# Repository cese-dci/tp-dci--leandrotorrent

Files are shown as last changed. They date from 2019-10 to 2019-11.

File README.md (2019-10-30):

El trabajo consiste en una primera placa para el proyecto final de la CESE:
https://docs.google.com/document/d/1wCjeIKm8gcKpIWY8Q068zwM_yTZGFjd9SOWhoT_4LNc/edit?usp=sharing

El proyecto consiste en un equipo capaz de conectar dispositivos con salida de datos RS-232 o RS-485 hacia una red Ethernet. 
La placa cuenta con:
- Drivers MAX3222 e ISL83485.
- Microcontrolador MSP430F5438A .
- Memorias 24LC256 para almacenamiento de web embebida (para configuracion y monitoreo).
- Modulo WIZNET para salida de datos hacia red Ethernet.

La hoja principal del esquematico se dirige a cada una de las partes que conforman la placa, siendo estas:
- Alimentacion
- Microcontrolador
- Drivers Serie
- Memorias 
- Modulo Wiznet

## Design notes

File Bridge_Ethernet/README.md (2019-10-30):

Comenzar a ver Esquemático desde el archivo "Bridge_Ethernet.sch"

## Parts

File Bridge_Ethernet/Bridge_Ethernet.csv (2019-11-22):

Id | Designator | Package | Quantity | Designation | Supplier and ref
1 | J4,J3 | PinSocket_1x06_P2.54mm_Vertical | 2 | Conn_01x06
2 | U7 | PZ100 | 1 | MSP430F5438A
3 | J5 | PinHeader_2x07_P1.27mm_Vertical | 1 | Conn_2Rows-13Pins
4 | C1,C2,C3,C4,C5,C6,C7,C8,C9,C10,C11,C12,C13,C14,C15,C16,C17,C18,C20,C21,C22,C26,C27,C28,C29,C30,C31,C32,C33,C34,C35,C36,C37 | C_0805_2012Metric | 33 | 0.1uF
5 | C19 | C_0805_2012Metric | 1 | 470nF
6 | C23 | C_0805_2012Metric | 1 | 22uF
7 | C24 | C_0805_2012Metric | 1 | 220uF
8 | C25 | C_0805_2012Metric | 1 | 10uF
9 | D1,D2,D3,D4,D9,D10,D11,D12 | SOT95P280X125-3N | 8 | GL05T-E3-08
10 | D5 | TO-269AA | 1 | MB2S
11 | D6 | D_SOD-123 | 1 | BZT52BC30-7
12 | D7 | LED_0805_2012Metric | 1 | VCC_5V
13 | D8 | D_MiniMELF | 1 | 10MQ060N
14 | F1 | Fuse_0805_2012Metric | 1 | Polyswitch
15 | J1,J2 | PinSocket_1x04_P1.27mm_Vertical | 2 | Conn_01x04_Female
16 | J7 | PinSocket_1x04_P1.27mm_Vertical | 1 | Conn_01x04_Male
17 | L1 | L_7.3x7.3_H4.5 | 1 | 330uH
18 | R1,R2,R3,R4,R9,R10,R11,R12 | R_0805_2012Metric | 8 | 4K7
19 | R5,R6 | R_0805_2012Metric | 2 | 10K
20 | R7 | R_0805_2012Metric | 1 | 47K
21 | R8 | R_0805_2012Metric | 1 | 470
22 | U1,U3,U10,U12 | SOIC127P1032X265-20N | 4 | MAX3222CDW
23 | U2,U4,U11,U13 | SOIC127P600X175-8N | 4 | ISL83485
24 | U5,U6 | SOIC127P600X175-8N | 2 | 24LC256
25 | U8 | SOIC-14W_7.5x9mm_P1.27mm | 1 | LM2574M-5
26 | U9 | DD-3 | 1 | REG1117
27 | H1,H2,H3,H4 | MountingHole_2.5mm_Pad | 4 | MountingHole

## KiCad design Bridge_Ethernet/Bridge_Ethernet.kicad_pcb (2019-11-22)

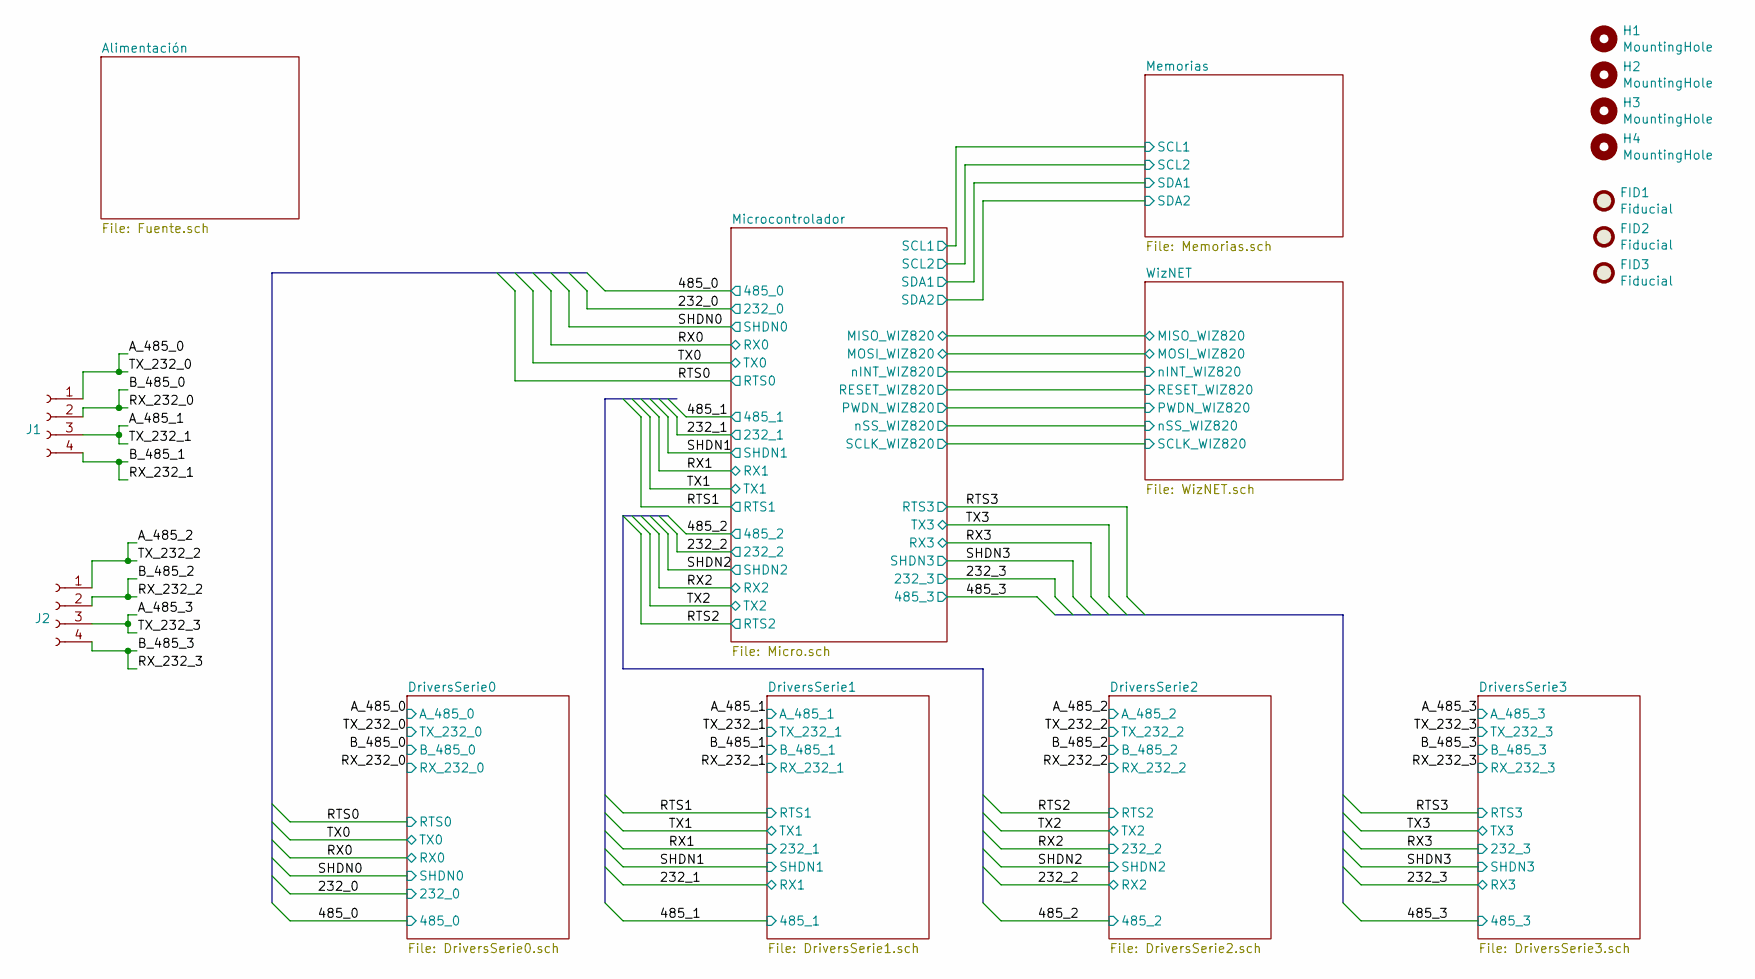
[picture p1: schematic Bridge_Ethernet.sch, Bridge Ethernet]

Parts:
FID1, FID2, FID3: Fiducial; Fiducial_0.5mm_Mask1mm
H1, H2, H3, H4: MountingHole; MountingHole_2.5mm_Pad
J1, J2: Conn_01x04_Female; PinSocket_1x04_P1.27mm_Vertical

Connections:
/A_485_0: J1.1; also elsewhere on the board
/A_485_1: J1.3; also elsewhere on the board
/A_485_2: J2.1; also elsewhere on the board
/A_485_3: J2.3; also elsewhere on the board
/B_485_0: J1.2; also elsewhere on the board
/B_485_1: J1.4; also elsewhere on the board
/B_485_2: J2.2; also elsewhere on the board
/B_485_3: J2.4; also elsewhere on the board

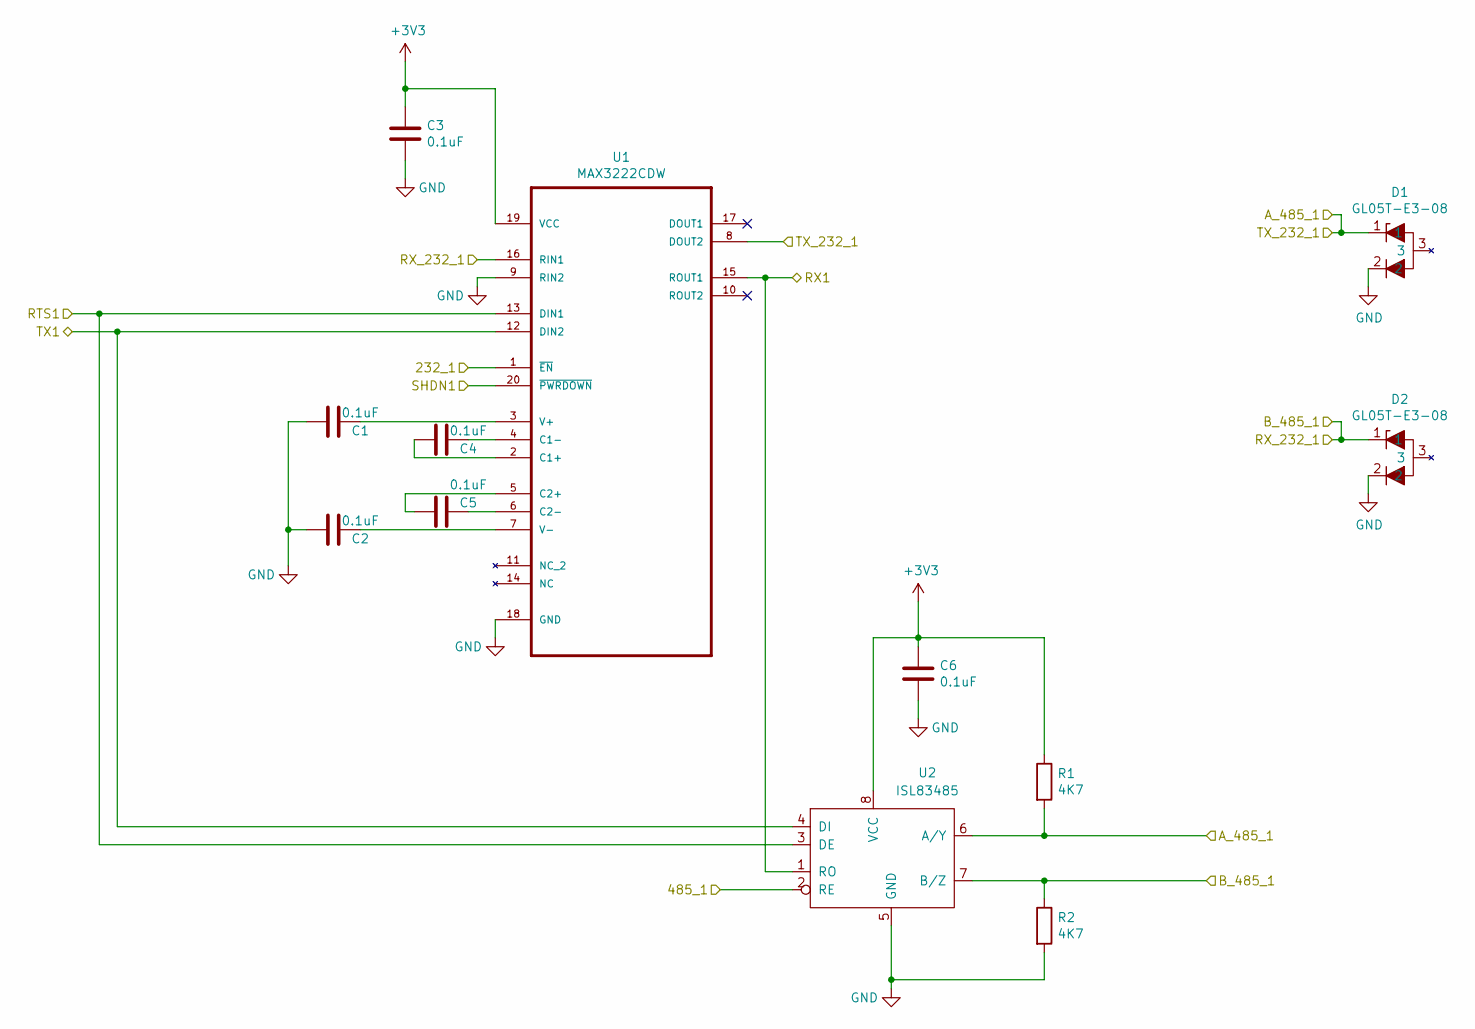
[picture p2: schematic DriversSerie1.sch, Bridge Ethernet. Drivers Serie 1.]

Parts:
C1, C2, C3, C4, C5, C6: 0.1uF; C_0805_2012Metric
D1, D2: GL05T-E3-08; SOT95P280X125-3N
R1, R2: 4K7; R_0805_2012Metric
U1: MAX3222CDW; SOIC127P1032X265-20N
U2: ISL83485; SOIC127P600X175-8N

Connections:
/232_1: U1.15 (ROUT1), U2.1 (RO); also elsewhere on the board
/485_1: U2.2 (RE); also elsewhere on the board
/A_485_1: D1.1, R1.2, U1.8 (DOUT2), U2.6 (A/Y); also elsewhere on the board
/B_485_1: D2.1, R2.1, U1.16 (RIN1), U2.7 (B/Z); also elsewhere on the board
/RTS1: U1.13 (DIN1), U2.3 (DE); also elsewhere on the board
/RX1: U1.1 (~EN); also elsewhere on the board
/SHDN1: U1.20 (~PWRDOWN); also elsewhere on the board
/TX1: U1.12 (DIN2), U2.4 (DI); also elsewhere on the board
GND: C1.2, C2.2, C3.2, C6.2, D1.2, D2.2, R2.2, U1.9 (RIN2), U1.18 (GND), U2.5 (GND); also elsewhere on the board
unnamed: C1.1, U1.3 (V+)
unnamed: C2.1, U1.7 (V-)
unnamed: C4.1, U1.4 (C1-)
unnamed: C4.2, U1.2 (C1+)
unnamed: C5.1, U1.6 (C2-)
unnamed: C5.2, U1.5 (C2+)

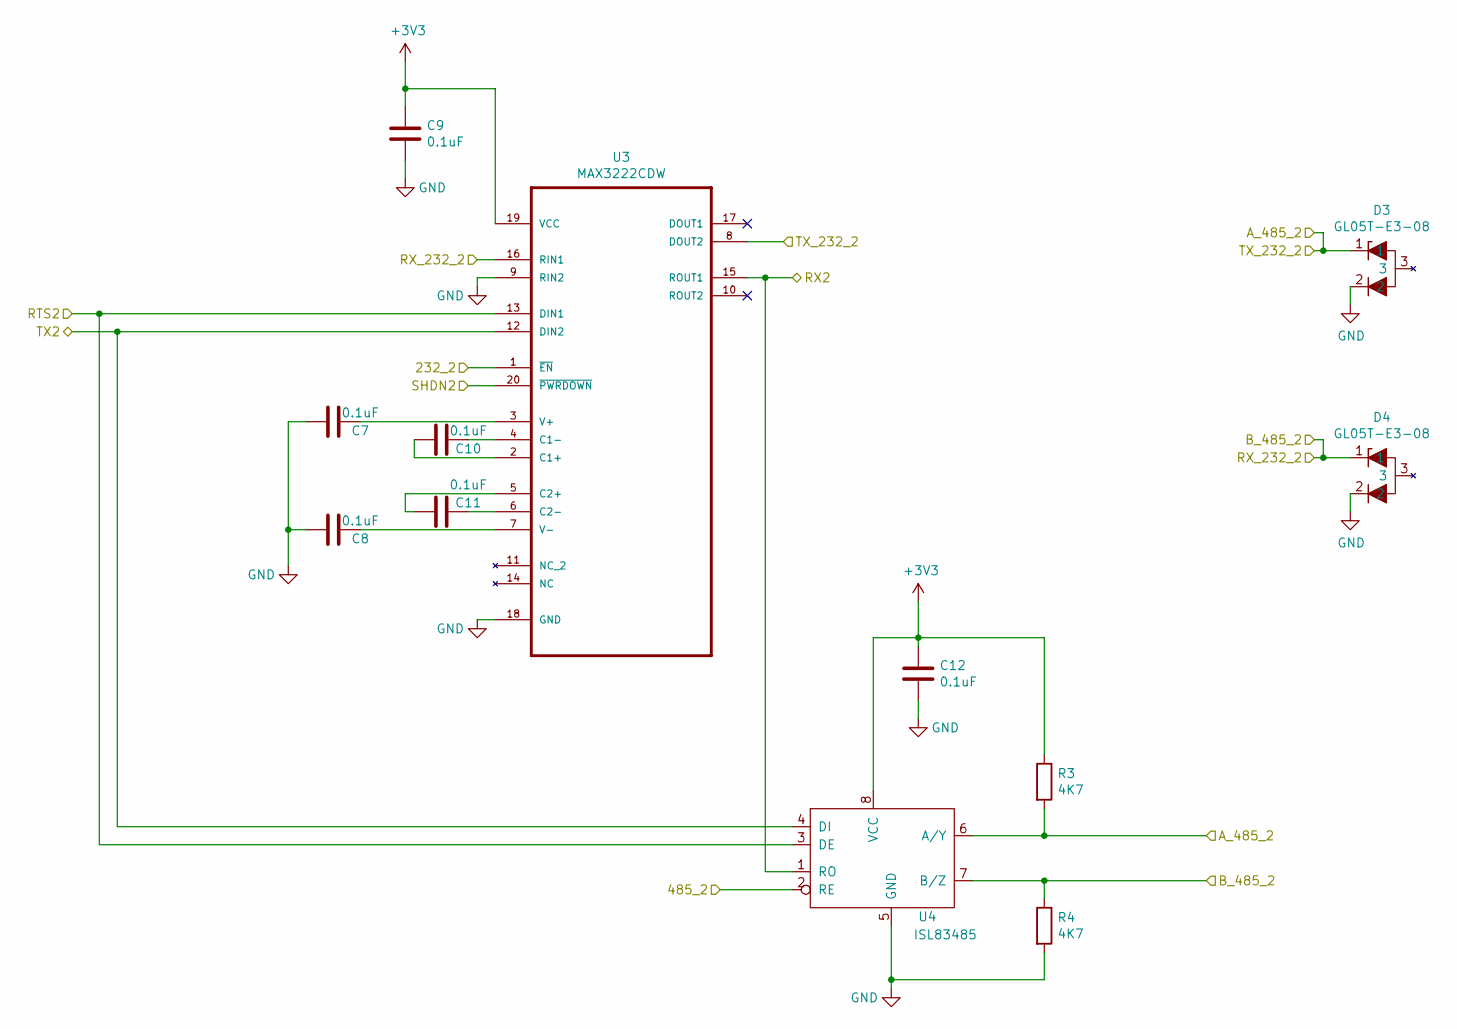
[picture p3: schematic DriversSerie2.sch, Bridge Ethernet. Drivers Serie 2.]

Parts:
C7, C8, C9, C10, C11, C12: 0.1uF; C_0805_2012Metric
D3, D4: GL05T-E3-08; SOT95P280X125-3N
R3, R4: 4K7; R_0805_2012Metric
U3: MAX3222CDW; SOIC127P1032X265-20N
U4: ISL83485; SOIC127P600X175-8N

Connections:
/232_2: U3.15 (ROUT1), U4.1 (RO); also elsewhere on the board
/485_2: U4.2 (RE); also elsewhere on the board
/A_485_2: D3.1, R3.2, U3.8 (DOUT2), U4.6 (A/Y); also elsewhere on the board
/B_485_2: D4.1, R4.1, U3.16 (RIN1), U4.7 (B/Z); also elsewhere on the board
/RTS2: U3.13 (DIN1), U4.3 (DE); also elsewhere on the board
/RX2: U3.1 (~EN); also elsewhere on the board
/SHDN2: U3.20 (~PWRDOWN); also elsewhere on the board
/TX2: U3.12 (DIN2), U4.4 (DI); also elsewhere on the board
GND: C7.2, C8.2, C9.2, C12.2, D3.2, D4.2, R4.2, U3.9 (RIN2), U3.18 (GND), U4.5 (GND); also elsewhere on the board
unnamed: C7.1, U3.3 (V+)
unnamed: C8.1, U3.7 (V-)
unnamed: C10.1, U3.4 (C1-)
unnamed: C10.2, U3.2 (C1+)
unnamed: C11.1, U3.6 (C2-)
unnamed: C11.2, U3.5 (C2+)

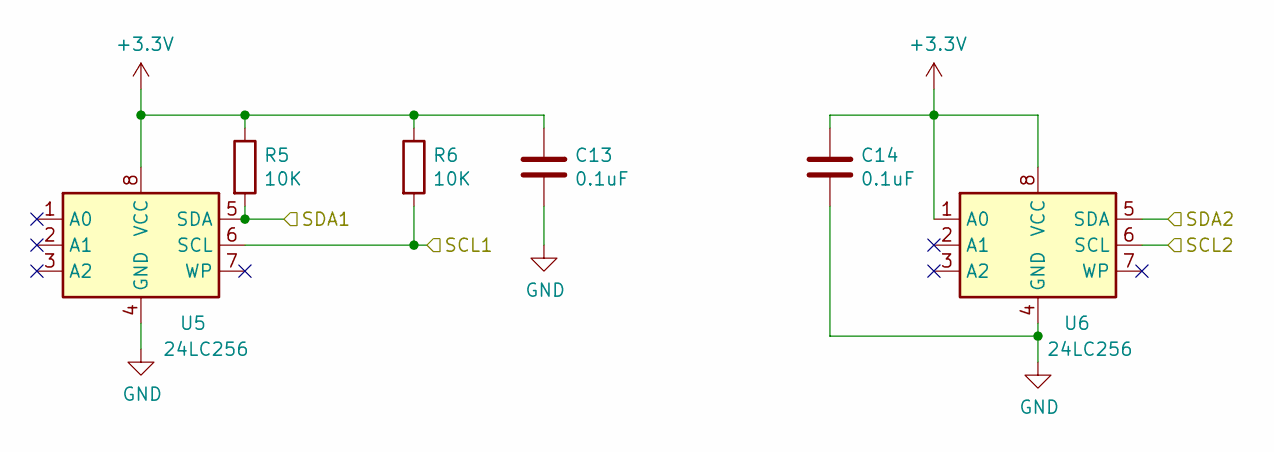
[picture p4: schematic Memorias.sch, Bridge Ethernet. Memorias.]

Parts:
C13, C14: 0.1uF; C_0805_2012Metric
R5, R6: 10K; R_0805_2012Metric
U5, U6: 24LC256; SOIC127P600X175-8N

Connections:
/Memorias/SCL1: R6.2, U5.6 (SCL); also elsewhere on the board
/Memorias/SCL2: U6.6 (SCL); also elsewhere on the board
/Memorias/SDA1: R5.2, U5.5 (SDA); also elsewhere on the board
/Memorias/SDA2: U6.5 (SDA); also elsewhere on the board
GND: C13.2, C14.2, U5.4 (GND), U6.4 (GND); also elsewhere on the board

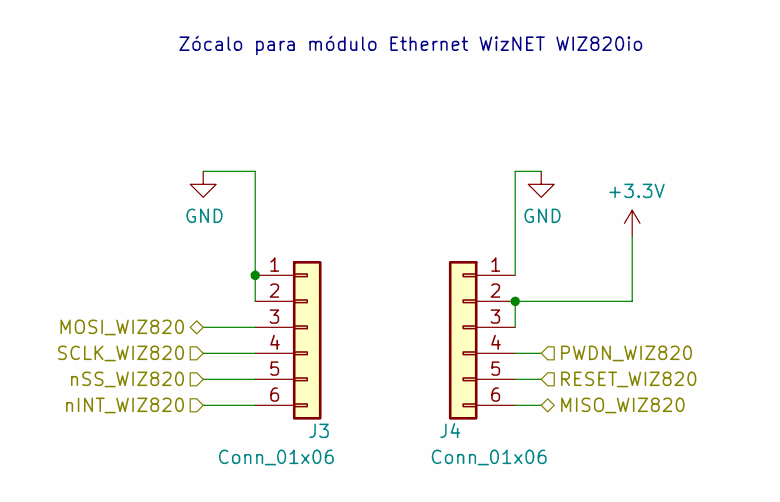
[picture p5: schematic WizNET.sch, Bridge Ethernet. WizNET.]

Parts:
J3, J4: Conn_01x06; PinSocket_1x06_P2.54mm_Vertical

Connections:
/Microcontrolador/MISO_WIZ820: J4.6; also elsewhere on the board
/Microcontrolador/MOSI_WIZ820: J3.3; also elsewhere on the board
/Microcontrolador/PWDN_WIZ820: J4.4; also elsewhere on the board
/Microcontrolador/RESET_WIZ820: J4.5; also elsewhere on the board
/Microcontrolador/SCLK_WIZ820: J3.4; also elsewhere on the board
/Microcontrolador/nINT_WIZ820: J3.6; also elsewhere on the board
/Microcontrolador/nSS_WIZ820: J3.5; also elsewhere on the board
GND: J3.1, J3.2, J4.1; also elsewhere on the board

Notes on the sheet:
Zócalo para módulo Ethernet WizNET WIZ820io

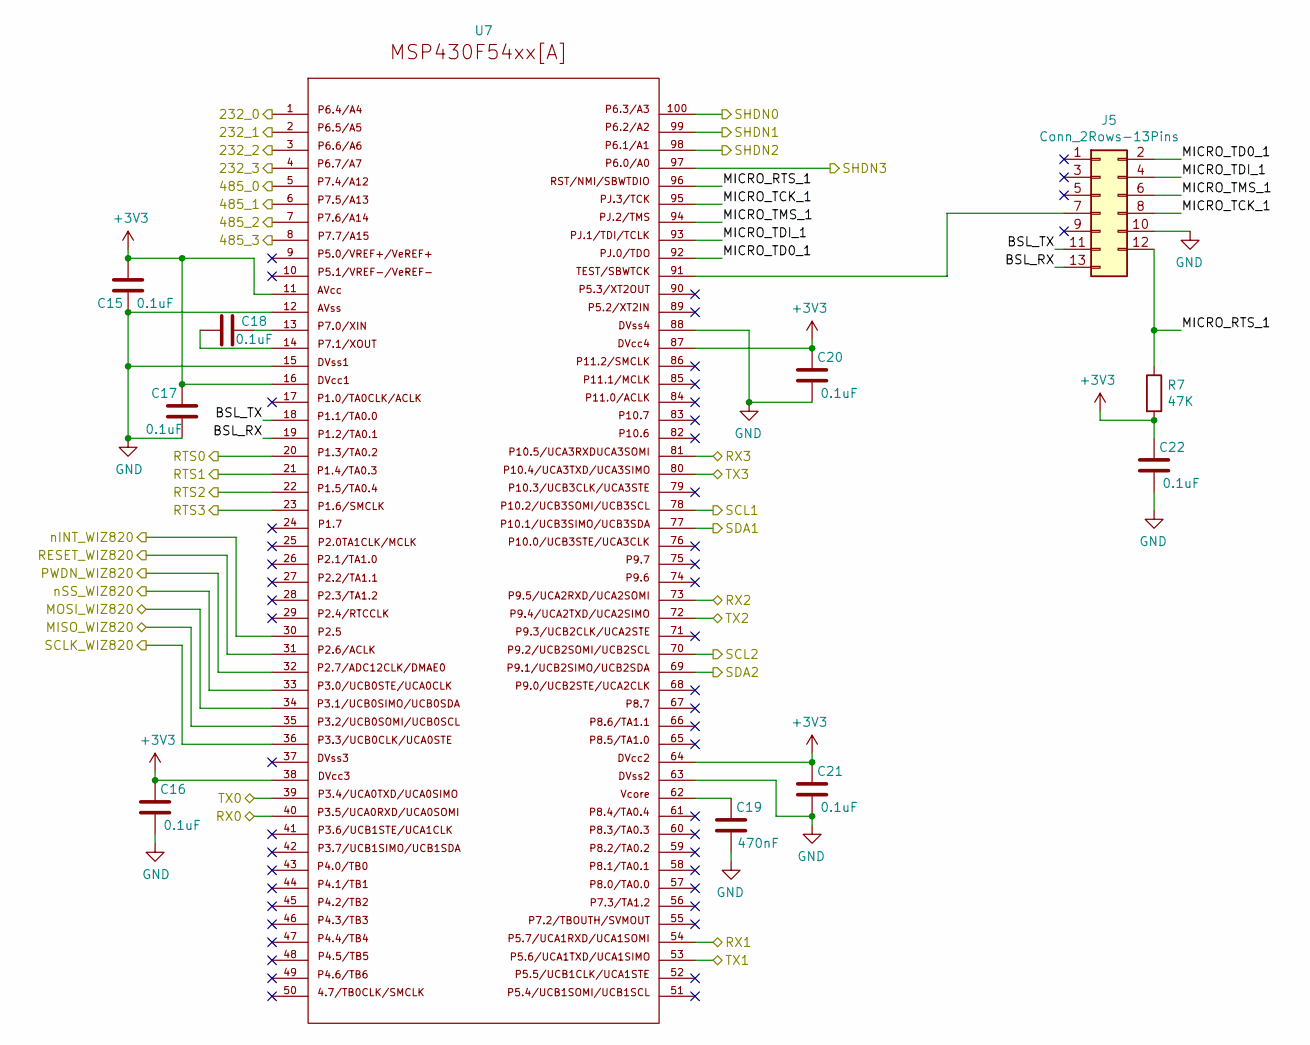
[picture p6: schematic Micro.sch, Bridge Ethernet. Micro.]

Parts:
C15, C16, C17, C18, C20, C21, C22: 0.1uF; C_0805_2012Metric
C19: 470nF; C_0805_2012Metric
J5: Conn_2Rows-13Pins; PinHeader_2x07_P1.27mm_Vertical
R7: 47K; R_0805_2012Metric
U7: MSP430F5438A; PZ100

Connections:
/232_0: U7.1; also elsewhere on the board
/232_1: U7.2; also elsewhere on the board
/232_2: U7.3; also elsewhere on the board
/232_3: U7.4; also elsewhere on the board
/485_0: U7.5; also elsewhere on the board
/485_1: U7.6; also elsewhere on the board
/485_2: U7.7; also elsewhere on the board
/485_3: U7.8; also elsewhere on the board
/Memorias/SCL1: U7.78; also elsewhere on the board
/Memorias/SCL2: U7.70; also elsewhere on the board
/Memorias/SDA1: U7.77; also elsewhere on the board
/Memorias/SDA2: U7.69; also elsewhere on the board
/Microcontrolador/BSL_RX: J5.13, U7.19
/Microcontrolador/BSL_TX: J5.11, U7.18
/Microcontrolador/MICRO_RTS_1: J5.12, R7.1, U7.96
/Microcontrolador/MICRO_TCK_1: J5.8, U7.95
/Microcontrolador/MICRO_TD0_1: J5.2, U7.92
/Microcontrolador/MICRO_TDI_1: J5.4, U7.93
/Microcontrolador/MICRO_TMS_1: J5.6, U7.94
/Microcontrolador/MISO_WIZ820: U7.35; also elsewhere on the board
/Microcontrolador/MOSI_WIZ820: U7.34; also elsewhere on the board
/Microcontrolador/PWDN_WIZ820: U7.32; also elsewhere on the board
/Microcontrolador/RESET_WIZ820: U7.31; also elsewhere on the board
/Microcontrolador/SCLK_WIZ820: U7.36; also elsewhere on the board
/Microcontrolador/nINT_WIZ820: U7.30; also elsewhere on the board
/Microcontrolador/nSS_WIZ820: U7.33; also elsewhere on the board
/RTS0: U7.20; also elsewhere on the board
/RTS1: U7.21; also elsewhere on the board
/RTS2: U7.22; also elsewhere on the board
/RTS3: U7.23; also elsewhere on the board
/RX0: U7.40; also elsewhere on the board
/RX1: U7.54; also elsewhere on the board
/RX2: U7.73; also elsewhere on the board
/RX3: U7.81; also elsewhere on the board
/SHDN0: U7.100; also elsewhere on the board
/SHDN1: U7.99; also elsewhere on the board
/SHDN2: U7.98; also elsewhere on the board
/SHDN3: U7.97; also elsewhere on the board
/TX0: U7.39; also elsewhere on the board
/TX1: U7.53; also elsewhere on the board
/TX2: U7.72; also elsewhere on the board
/TX3: U7.80; also elsewhere on the board
GND: C15.2, C16.2, C17.2, C19.2, C20.2, C21.2, C22.2, J5.10, U7.12, U7.15, U7.63, U7.88; also elsewhere on the board
unnamed: C18.1, U7.13
unnamed: C18.2, U7.14
unnamed: C19.1, U7.62
unnamed: J5.7, U7.91

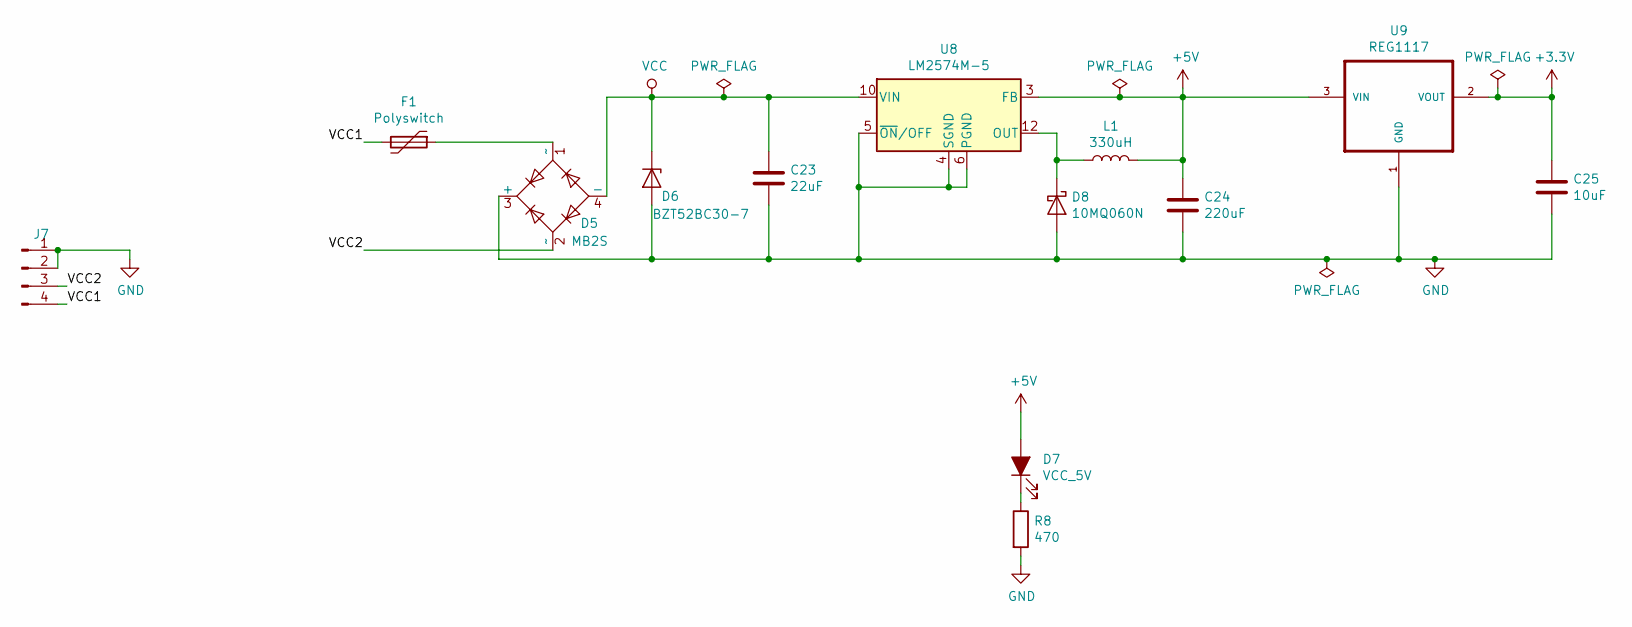
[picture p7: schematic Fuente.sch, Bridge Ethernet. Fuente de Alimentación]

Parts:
C23: 22uF; C_0805_2012Metric
C24: 220uF; C_0805_2012Metric
C25: 10uF; C_0805_2012Metric
D5: MB2S; TO-269AA
D6: BZT52BC30-7; D_SOD-123
D7: VCC_5V; LED_0805_2012Metric
D8: 10MQ060N; D_MiniMELF
F1: Polyswitch; Fuse_0805_2012Metric
J7: Conn_01x04_Male; PinSocket_1x04_P1.27mm_Vertical
L1: 330uH; L_7.3x7.3_H4.5
R8: 470; R_0805_2012Metric
U8: LM2574M-5; SOIC-14W_7.5x9mm_P1.27mm
U9: REG1117; DD-3

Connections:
+5V: C24.1, D7.2 (A), L1.2, U8.3 (FB), U9.3 (VIN)
/Alimentación/VCC1: F1.2, J7.4
/Alimentación/VCC2: D5.2 (~~), J7.3
GND: C23.2, C24.2, C25.2, D5.3 (+), D6.2 (A), D8.2 (A), J7.1, J7.2, R8.2, U8.4 (SGND), U8.5 (~ON~/OFF), U8.6 (PGND), U9.1 (GND); also elsewhere on the board
unnamed: D5.1 (~~), F1.1
unnamed: D7.1 (K), R8.1
unnamed: D8.1 (K), L1.1, U8.12 (OUT)
VCC: C23.1, D5.4 (-), D6.1 (K), U8.10 (VIN)

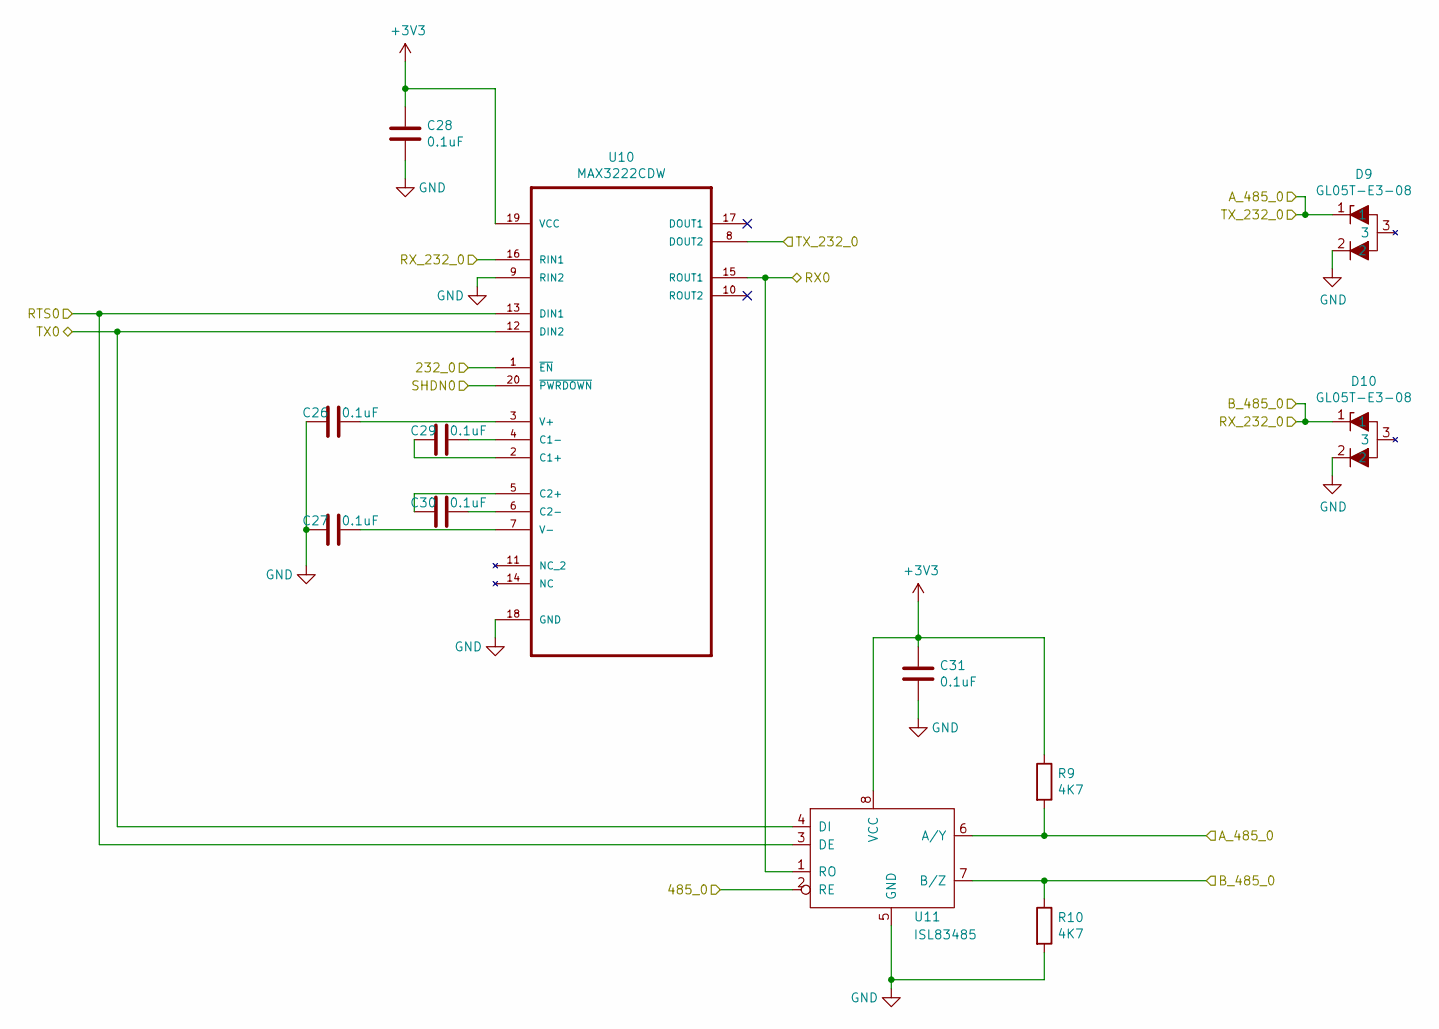
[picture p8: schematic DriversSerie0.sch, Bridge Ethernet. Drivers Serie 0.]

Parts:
C26, C27, C28, C29, C30, C31: 0.1uF; C_0805_2012Metric
D9, D10: GL05T-E3-08; SOT95P280X125-3N
R9, R10: 4K7; R_0805_2012Metric
U10: MAX3222CDW; SOIC127P1032X265-20N
U11: ISL83485; SOIC127P600X175-8N

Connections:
/232_0: U10.1 (~EN); also elsewhere on the board
/485_0: U11.2 (RE); also elsewhere on the board
/A_485_0: D9.1, R9.2, U10.8 (DOUT2), U11.6 (A/Y); also elsewhere on the board
/B_485_0: D10.1, R10.1, U10.16 (RIN1), U11.7 (B/Z); also elsewhere on the board
/RTS0: U10.13 (DIN1), U11.3 (DE); also elsewhere on the board
/RX0: U10.15 (ROUT1), U11.1 (RO); also elsewhere on the board
/SHDN0: U10.20 (~PWRDOWN); also elsewhere on the board
/TX0: U10.12 (DIN2), U11.4 (DI); also elsewhere on the board
GND: C26.2, C27.2, C28.2, C31.2, D9.2, D10.2, R10.2, U10.9 (RIN2), U10.18 (GND), U11.5 (GND); also elsewhere on the board
unnamed: C26.1, U10.3 (V+)
unnamed: C27.1, U10.7 (V-)
unnamed: C29.1, U10.4 (C1-)
unnamed: C29.2, U10.2 (C1+)
unnamed: C30.1, U10.6 (C2-)
unnamed: C30.2, U10.5 (C2+)

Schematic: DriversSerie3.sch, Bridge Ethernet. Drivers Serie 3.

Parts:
C32, C33, C34, C35, C36, C37: 0.1uF; C_0805_2012Metric
D11, D12: GL05T-E3-08; SOT95P280X125-3N
R11, R12: 4K7; R_0805_2012Metric
U12: MAX3222CDW; SOIC127P1032X265-20N
U13: ISL83485; SOIC127P600X175-8N

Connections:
/232_3: U12.15 (ROUT1), U13.1 (RO); also elsewhere on the board
/485_3: U13.2 (RE); also elsewhere on the board
/A_485_3: D11.1, R11.2, U12.8 (DOUT2), U13.6 (A/Y); also elsewhere on the board
/B_485_3: D12.1, R12.1, U12.16 (RIN1), U13.7 (B/Z); also elsewhere on the board
/RTS3: U12.13 (DIN1), U13.3 (DE); also elsewhere on the board
/RX3: U12.1 (~EN); also elsewhere on the board
/SHDN3: U12.20 (~PWRDOWN); also elsewhere on the board
/TX3: U12.12 (DIN2), U13.4 (DI); also elsewhere on the board
GND: C32.2, C33.2, C34.2, C37.2, D11.2, D12.2, R12.2, U12.9 (RIN2), U12.18 (GND), U13.5 (GND); also elsewhere on the board
unnamed: C32.1, U12.3 (V+)
unnamed: C33.1, U12.7 (V-)
unnamed: C35.1, U12.4 (C1-)
unnamed: C35.2, U12.2 (C1+)
unnamed: C36.1, U12.6 (C2-)
unnamed: C36.2, U12.5 (C2+)

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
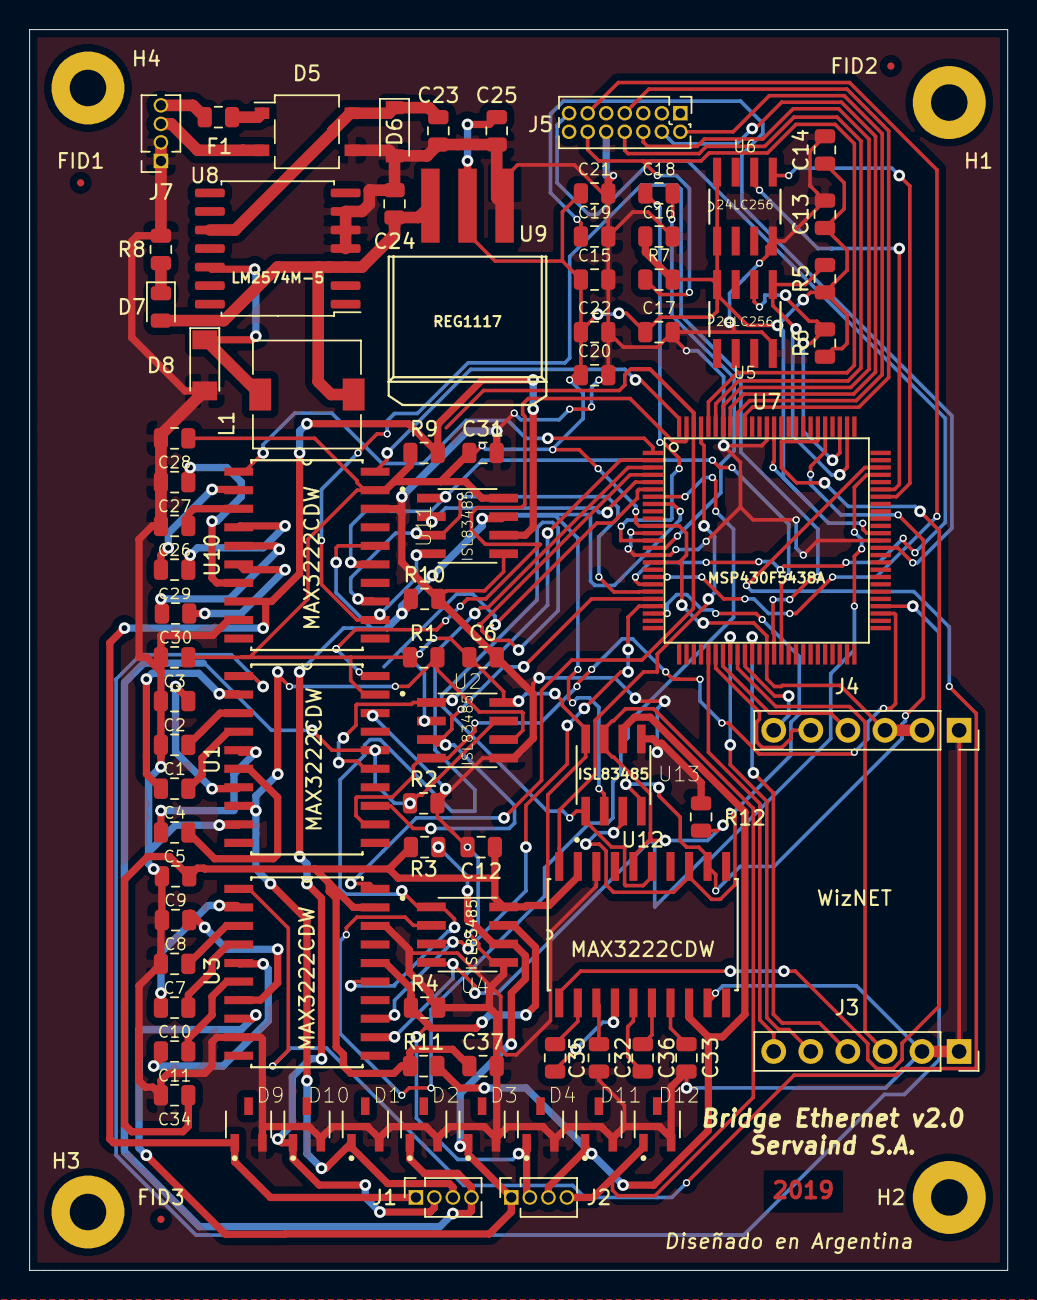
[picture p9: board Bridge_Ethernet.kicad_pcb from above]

Board: 2 copper layers, 67.0 x 85.0 mm, 89 parts (0 on the bottom side), 87 nets.

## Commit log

2019-10-30 Esquemático Finalizado
    [Bridge_Ethernet.kicad_pcb, Bridge_Ethernet.sch, DriversSerie0.sch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]
2019-10-31 Esquemático Finalizado, sin warnings. Haciendo asignaciones de footprints
    [DriversSerie0.sch, DriversSerie1.sch, DriversSerie2.sch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]
2019-10-31 Esquemático Finalizado. Asignaciones Realizadas. Comienzo de PCB.
    [Bridge_Ethernet.sch, DriversSerie0.sch, DriversSerie1.sch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]
2019-11-01 Esquemático Finalizado. Asignaciones Realizadas. Componentes acomodados en PCB.
    [Bridge_Ethernet.sch, DriversSerie0.sch, DriversSerie1.sch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]
2019-11-01 Esquemático Finalizado. Asignaciones Realizadas. Componentes acomodados en PCB v2.0.
    [Bridge_Ethernet.kicad_pcb]
2019-11-01 Esquemático Finalizado. Asignaciones Realizadas. Reacomodamiento de componentes. Inicio de Ruteo.
    [Bridge2.kicad_pcb, DriversSerie0.sch, DriversSerie1.sch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]
2019-11-01 Esquemático Finalizado. Asignaciones Realizadas. Reacomodamiento de componentes. Ruteo en Proceso.
    [Bridge_Ethernet.kicad_pcb]
2019-11-08 Esquemático Finalizado. Asignaciones Realizadas. Reacomodamiento de componentes. Ruteo Finalizado.
    [Bridge_Ethernet.kicad_pcb]
2019-11-17 v2.0. Faltan algunos componentes 3D. Correciones relizadas.
    [Bridge2.kicad_pcb, Bridge_Ethernet.kicad_pcb, Bridge_Ethernet.sch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]
2019-11-22 Correciones relizadas.
    [Bridge_Ethernet.csv, Bridge_Ethernet.kicad_pcb, Bridge_Ethernet.sch]
